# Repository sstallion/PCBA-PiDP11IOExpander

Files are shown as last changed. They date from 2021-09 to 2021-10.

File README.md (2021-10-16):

# PiDP-11 I/O Expander PCBA

This repository contains the PCBA design files for a 16-bit TTL compatible I/O
expander for the [PiDP-11][1] and [Raspberry Pi][2]. Design files are intended
to be viewed using [Altium Designer][3]. Releases may also be uploaded to the
standalone [Altium 365 Viewer][4] for free.

Project documentation is hosted on [Hackaday][5] and assembled boards are
available for purchase from [Tindie][6].

Test Fixture

## Details

A test fixture was created to support functional testing of PCBs. The fixture is
based on a [Merifix MF300][7] with a custom interposer controlled by a [Total
Phase Aardvark][8] and a [B&K Precision 1785B][9] benchtop power supply.
Functional tests were developed in Python using the [OpenHTF][10] hardware
testing framework.

To execute functional tests, follow these steps:

1. Install the [Chocolatey][11] package manager for Windows.
2. Using Windows Explorer, navigate to the `Python` folder and right click on
   the `setup.cmd` command file and select `Run as administrator`. This will
   install dependencies and create a Python virtual environment for testing.
3. Double click on the `fct_station.cmd` command file in the `Python` folder to
   start the FCT test station.
4. You can interact with the test station from either the command window, or by
   pointing a browser to http://localhost:4444.
5. Enter the DUT serial number to begin testing using the keyboard or hand
   scanner (eg. Symbol LS2208).

For more details, see the latest release on [GitHub][12].

## Contributing

Pull requests are welcome! See [CONTRIBUTING.md] for more details.

## License

Source code in this repository is licensed under a Simplified BSD License. See
[LICENSE.txt] for more details.

[1]: https://obsolescence.wixsite.com/obsolescence/pidp-11
[2]: https://www.raspberrypi.org/
[3]: https://www.altium.com/altium-designer/
[4]: https://www.altium.com/viewer/
[5]: https://hackaday.io/project/181311
[6]: https://www.tindie.com/products/24781
[7]: https://www.merifix.com/docs/Merifix-MF300-Brochure.pdf
[8]: https://www.totalphase.com/products/aardvark-i2cspi/
[9]: https://www.bkprecision.com/products/power-supplies/1785B-0-18vdc-0-5a-programmable-dc-supply-w-rs232-interface.html
[10]: https://github.com/google/openhtf
[11]: https://chocolatey.org/install
[12]: https://github.com/sstallion/PCBA-PiDP11IOExpander/releases/latest

[CONTRIBUTING.md]: CONTRIBUTING.md
[LICENSE.txt]: LICENSE.txt

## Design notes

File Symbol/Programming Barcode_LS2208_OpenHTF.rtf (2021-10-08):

OpenHTF - Scanner Parameter Settings Report LS2208

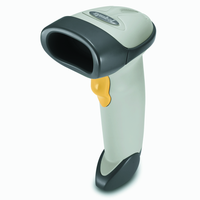
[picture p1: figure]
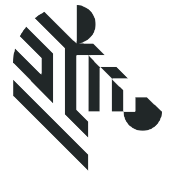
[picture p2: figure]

Summary Information
Report Type: Configuration name in Utility: Last Modified: Windows Filename: Plug-in Name: Notes: | Only parameters changed from defaults shown OpenHTF 08-Oct-21 Config File_LS2208_OpenHTF_2021.07.28.scncfg LS2208-COMMON MODELS v2.0-010
General Parameter Settings
Beeper Beeper Volume | Low^

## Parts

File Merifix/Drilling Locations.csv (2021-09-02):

TP1 | -0.700 | 0.113 | S075 | 3V3 Test Probe
TP2 | -0.800 | 0.113 | S075 | SDA Test Probe
TP3 | -0.900 | 0.113 | S075 | SCL Test Probe
TP4 | -1.000 | 0.113 | S075 | INT Test Probe
TP5 | 0.900 | 0.613 | S075 | 5V Test Probe
TP6 | 1.000 | 0.613 | S075 | GND Test Probe
TP7 | -0.300 | 0.613 | S075 | GP0.0 Test Probe
TP8 | -0.400 | 0.613 | S075 | GP0.1 Test Probe
TP9 | -0.500 | 0.613 | S075 | GP0.2 Test Probe
TP10 | -0.600 | 0.613 | S075 | GP0.3 Test Probe
TP11 | -0.700 | 0.613 | S075 | GP0.4 Test Probe
TP12 | -0.800 | 0.613 | S075 | GP0.5 Test Probe
TP13 | -0.900 | 0.613 | S075 | GP0.6 Test Probe
TP14 | -1.000 | 0.613 | S075 | GP0.7 Test Probe
TP15 | -0.300 | 0.513 | S075 | GP1.0 Test Probe
TP16 | -0.400 | 0.513 | S075 | GP1.1 Test Probe
TP17 | -0.500 | 0.513 | S075 | GP1.2 Test Probe
TP18 | -0.600 | 0.513 | S075 | GP1.3 Test Probe
TP19 | -0.700 | 0.513 | S075 | GP1.4 Test Probe
TP20 | -0.800 | 0.513 | S075 | GP1.5 Test Probe
TP21 | -0.900 | 0.513 | S075 | GP1.6 Test Probe
TP22 | -1.000 | 0.513 | S075 | GP1.7 Test Probe
LP1 | -1.113 | 0.000 | S3 | Bottom Left Locating Probe
LP2 | -1.113 | 0.726 | S3 | Top Left Locating Probe
LP3 | 1.113 | 0.000 | S3 | Bottom Right Locating Probe
LP4 | 1.113 | 0.726 | S3 | Top Right Locating Probe
H1 | -0.650 | 0.363 | H | Left Hold-Down Post
H2 | 0.000 | 0.683 | H | Top Hold-Down Post
H3 | 0.650 | 0.363 | H | Right Hold-Down Post
M1 | -1.450 | 1.000 | M | Bottom Left Mounting Hole
M2 | -1.450 | 3.100 | M | Top Left Mounting Hole
M3 | 1.450 | 1.000 | M | Bottom Right Mounting Hole
M4 | 1.450 | 3.100 | M | Top Right Mounting Hole

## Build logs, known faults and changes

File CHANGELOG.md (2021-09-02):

# Changelog

All notable changes to this project will be documented in this file.

The format is based on [Keep a Changelog](https://keepachangelog.com/en/1.0.0/).

## [Unreleased]

## [Revision A] - 2021-09-01

Initial release

[Unreleased]: https://github.com/sstallion/PCBA-PiDP11IOExpander/compare/RevA...HEAD
[Revision A]: https://github.com/sstallion/PCBA-PiDP11IOExpander/releases/tag/RevA

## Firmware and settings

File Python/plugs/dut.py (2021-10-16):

# Copyright (C) 2021 Steven Stallion <sstallion@gmail.com>
#
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
from array import array

from openhtf import conf
from openhtf_common.plugs import Aardvark, RequiresPlug

conf.declare('dut_i2c_address',
             default_value=0x20,
             description='I2C address of DUT.')

conf.declare('dut_i2c_bitrate',
             default_value=100,
             description='I2C bit rate (in kHz) for DUT.')

conf.declare('dut_i2c_pullups',
             default_value=True,
             description='Enable I2C pullups for DUT.')


class DUT(RequiresPlug):
    """Plug that provides access to a PiDP-11 I/O Expander DUT.

    The heart of the DUT is a Microchip MCP23016 I/O expander that
    communicates over I2C and is programmed using a Total Phase Aardvark.
    """
    NUMBER_OF_PORTS = 2
    NUMBER_OF_PINS_PER_PORT = 8

    @staticmethod
    def enumerate_ports():
        """Returns an iterator of tuples containing the primary port number
        followed by the secondary (eg. opposing) port number.
        """
        return zip(range(DUT.NUMBER_OF_PORTS), reversed(range(DUT.NUMBER_OF_PORTS)))

    @staticmethod
    def enumerate_pins():
        """Returns an interator of tuples containing the pin number followed
        by its bitmask.
        """
        return enumerate(map(lambda x: 1<<x, range(DUT.NUMBER_OF_PINS_PER_PORT)))

    @conf.inject_positional_args
    def __init__(self, dut_i2c_address, dut_i2c_bitrate, dut_i2c_pullups):
        super(DUT, self).__init__(aardvark=Aardvark)
        self._i2c_address = dut_i2c_address
        self.aardvark.set_i2c_bitrate(dut_i2c_bitrate)
        self.aardvark.set_i2c_pullups(dut_i2c_pullups)

    def get_data(self, port):
        self.logger.debug('Getting data for GP%d.', port)
        return self.aardvark.i2c_read_register(self._i2c_address, 0x00+port, 1)[0]

    def set_data(self, port, mask):
        self.logger.debug('Setting data for GP%d to 0x%02x.', port, mask)
        self.aardvark.i2c_write(self._i2c_address, array('B', [0x00+port, mask]))

    def get_direction(self, port):
        self.logger.debug('Getting direction for GP%d.', port)
        return self.aardvark.i2c_read_register(self._i2c_address, 0x06+port, 1)[0]

    def set_direction(self, port, mask):
        self.logger.debug('Setting direction for GP%d to 0x%02x.', port, mask)
        self.aardvark.i2c_write(self._i2c_address, array('B', [0x06+port, mask]))

    def get_interrupt_capture(self, port):
        self.logger.debug('Getting interrupt capture for GP%d.', port)
        return self.aardvark.i2c_read_register(self._i2c_address, 0x08+port, 1)[0]

    def clear_interrupt(self):
        self.logger.debug('Clearing interrupt.')
        for port, _ in DUT.enumerate_ports():
            self.get_interrupt_capture(port)

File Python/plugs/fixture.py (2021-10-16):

# Copyright (C) 2021 Steven Stallion <sstallion@gmail.com>
#
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
import time

from openhtf.util import conf
from openhtf_common.plugs import Aardvark, BK1785B, RequiresPlug

conf.declare(
    'fixture_psu_current',
    default_value=0.50,
    description='Current (in amps) to supply to fixture.')

conf.declare(
    'fixture_psu_voltage',
    default_value=5.0,
    description='Voltage (in volts) to supply to fixture.')

conf.declare(
    'fixture_settle_s',
    default_value=1.0,
    description='Time (in seconds) to wait after supplying power to fixture.')


class Fixture(RequiresPlug):
    """Plug that provides access to a PiDP-11 I/O Expander test fixture.

    The test fixture contains a simple interposer with discrete logic to
    connect or isolate I/O pins over GPIO and is programmed using a Total
    Phase Aardvark. Power is controlled using a B&K Precision BK1785B power
    supply over serial.

    Pin isolation is controlled using the 5V target power pins provided by the
    Aardvark. This signal is pulled down, effectively making it an additional
    GPIO output.
    """
    GPIO_A0  = 1<<2 # AA_GPIO_MISO (Pin 5)
    GPIO_A1  = 1<<3 # AA_GPIO_SCK  (Pin 7)
    GPIO_A2  = 1<<4 # AA_GPIO_MOSI (Pin 8)
    GPIO_INT = 1<<5 # AA_GPIO_SS   (Pin 9)

    GPIO_DIRECTION = GPIO_A0 | GPIO_A1 | GPIO_A2 #| GPIO_INT

    @conf.inject_positional_args
    def __init__(self, fixture_psu_current, fixture_psu_voltage, fixture_settle_s):
        super(Fixture, self).__init__(aardvark=Aardvark, psu=BK1785B)
        self.aardvark.set_gpio_direction(Fixture.GPIO_DIRECTION)
        self.psu.set_current(fixture_psu_current)
        self.psu.set_voltage(fixture_psu_voltage)
        self.psu.set_output(True)

        self.logger.debug('Waiting for DUT to settle.')
        time.sleep(fixture_settle_s)

    def connect_pins(self, pin):
        # Test probes were connected in reversed order. Rather than rewire the
        # test fixture, we account for it here:
        reversed_pin = pin ^ 0x7

        self.logger.debug('Connecting GP0 and GP1 pin %d.', pin)
        mask = sum(map(lambda x: reversed_pin & 1<<x[0] and x[1],
                       enumerate([Fixture.GPIO_A0, Fixture.GPIO_A1, Fixture.GPIO_A2])))
        self.aardvark.gpio_set(mask)
        self.aardvark.set_target_power(True)

    def isolate_pins(self):
        self.logger.debug('Isolating GP0 and GP1 pins.')
        self.aardvark.set_target_power(False)

    def has_interrupt(self):
        self.logger.debug('Checking for interrupt.')
        mask = self.aardvark.gpio_get()
        return mask & Fixture.GPIO_INT == 0

    def wait_for_interrupt(self):
        self.logger.debug('Waiting for interrupt.')
        mask = self.aardvark.gpio_get()
        while True:
            if mask & Fixture.GPIO_INT == 0:
                break
            mask = self.aardvark.gpio_wait()
